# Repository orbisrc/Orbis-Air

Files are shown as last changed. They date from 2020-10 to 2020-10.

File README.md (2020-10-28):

## Orbis-Air



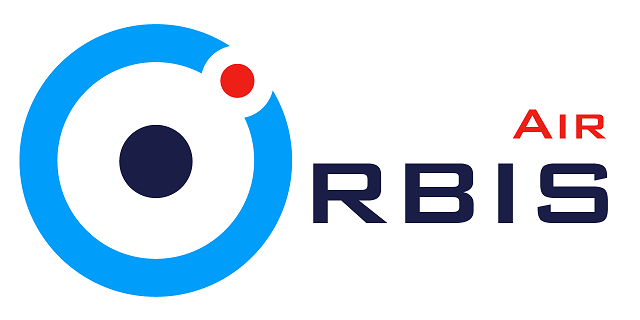
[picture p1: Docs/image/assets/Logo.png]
Orbis-Air


[Youtube: Orbis Air channel in Betaflight](https://youtu.be/BvFRO2qdrkg "Orbis Air channel in Betaflight")

[Youtube: Orbis Air DIY RC Transmitter](https://youtu.be/_WfU4lffqmU "Orbis Air DIY RC Transmitter")

[Thingverse: Orbis Air DIY RC Transmitter](https://www.thingiverse.com/thing:4635528 "Orbis Air DIY RC Transmitter")

Orbis Air is a transmitter project which anyone can make.
It includes:
- Drawings
- Shematic
- Software
- Assembly instructions

### Features
- Transmitter which anyone can make
- Built-in battery with charge from usb
- Connect with simulators via usb
- STM32 F4 processor
- Color 2.4' IPS screen
- Small size
- Gamepad format

### Done
- GUI
- RC channel settings
    - End point
    - Trim
    - Exponents
    - Inversion
    - Channel mapping
- Save/load settings
- Model memory
- Battery low warning
- Inactivity warning
- Screen brightness settings
- Call DFU bootloader from GUI
- PPM generator for external transmitter
- USB-HID for simulators. And tested this in Liftoff
- USB charger

### BOM

- SPI Screen - http://ali.onl/1EDp
- PCB Board STM32F407VET6 - http://ali.onl/1EDh
- Jumper V2 Hall Gimbal http://bgd.onl/7c
- EC11 Encoder http://ali.onl/1EDi
- B5K Potentiometr http://ali.onl/1EDg
- Potentiometr knob http://ali.onl/1EDq
- Micro USB Pcb http://ali.onl/1EDj
- 18500 LiIon battery http://ali.onl/1EDl
- Beeper http://ali.onl/1EDm
- TP5100 Battery charger http://ali.onl/1EDn
- Vibro motor http://ali.onl/1EDo
- DC-DC StepUp MT3608 http://ali.onl/1EDr
- DC-DC StepDown http://ali.onl/1EDs
- Transmitter JR module - Optional.  http://ali.onl/1EDt
- 17mm Pin header http://ali.onl/1EDu
- SMTS-103 or SMTS-102 Switch http://ali.onl/1EDv
- SPST for power switch http://ali.onl/1EDw

### Manual

 1. [Assembly manual](Docs/assembly.md)
 2. [Main schematic](Docs/shematic.md)
 3. [DFU driver install](Docs/dfu_dfivers_install.md)
 4. [Firmware update](Docs/firmware_udate.md)
 5. [First start](Docs/first_start.md)
 
### Developer Channel




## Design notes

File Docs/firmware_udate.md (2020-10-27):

# Firmware update
- Download and install [DfuSeDemo](https://www.st.com/en/development-tools/stsw-stm32080.html) 
- If you are uploading the firmware for the first time, close the BOOT and 3.3V contacts on the MCU PCB. If you need to update the firmware,  "settings -> info -> DFU mode"
- Connect the board to your computer.
- The jumper between BOOT and 3.3V can be removed
- STM32 download inteface will appear in the device manager
- Run DfuSeDemo

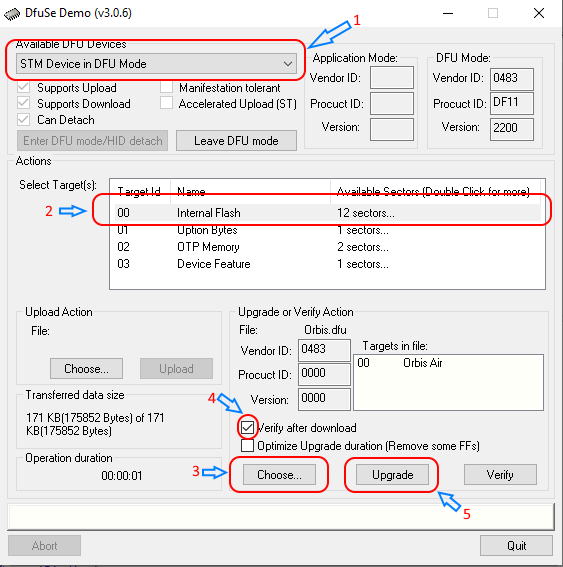
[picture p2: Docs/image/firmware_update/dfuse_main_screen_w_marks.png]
DfuSeDemo

1. Select "DFU Device in DFU Mode" 
2. Select "Internal flash"
3. Choose target firmware
4. Check "Verify after download"
5. Push button "Upgrade"

- After firmware update, turn off and turn on transmitter

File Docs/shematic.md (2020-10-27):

# Main circuit

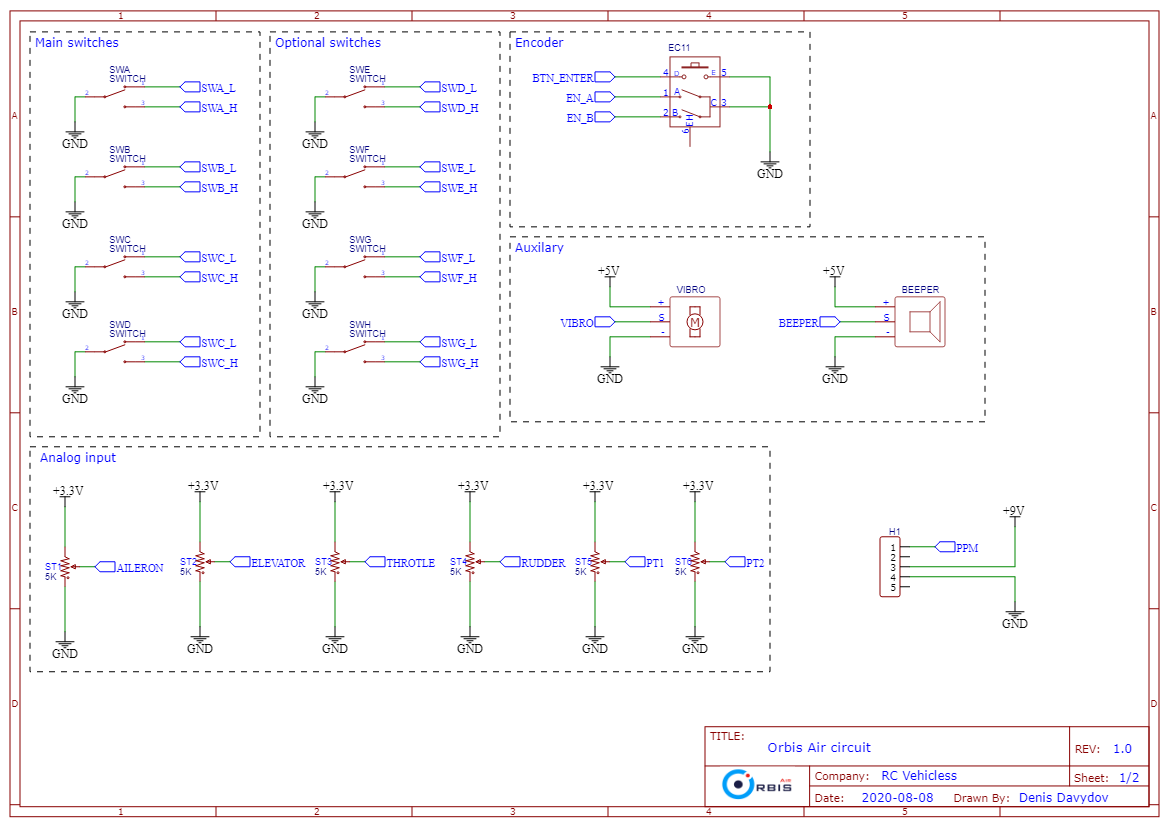
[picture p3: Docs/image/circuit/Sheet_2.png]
Circuit list 1


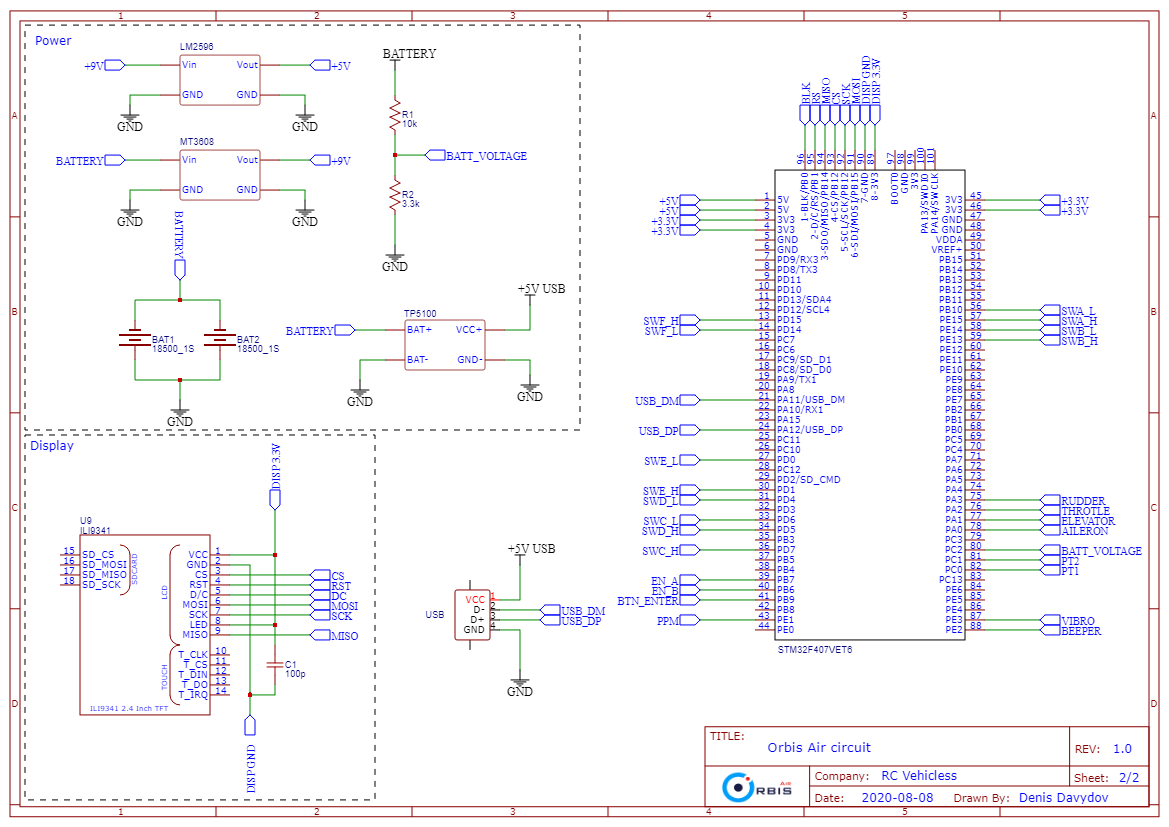
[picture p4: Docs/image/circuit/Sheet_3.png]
Circuit list 2


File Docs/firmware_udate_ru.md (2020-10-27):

# Firmware update
- Скачай и установи утилиту [DfuSeDemo](https://www.st.com/en/development-tools/stsw-stm32080.html) 
- На плате MCU замкни контаты BOOT и 3.3V. 
- Плату подключи к компьютеру. Перемычку между BOOT и 3.3V можно убрать
- В диспетчере устрйоств появится STM32 download inteface. Windows автоматически установит драйвера. 
- Запусти DfuSeDemo

DfuSeDemo
1. Выбери устройство
2. Выбери "Internal flash"
3. Выбери прошивку, которую надо загрузить в устройство.
4. Отметь "Verify after download"
5. Нажми "Upgrade"

- Когда закончится процесс обновления по, выключи и включи устройство

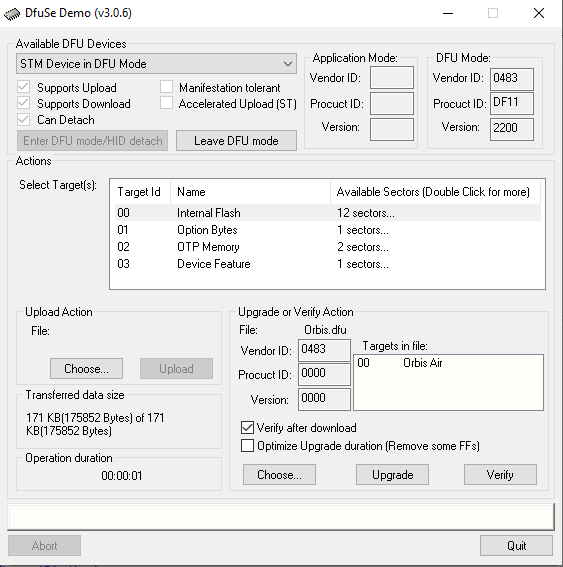
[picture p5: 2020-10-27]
Docs/image/firmware_update/dfuse_main_screen.png

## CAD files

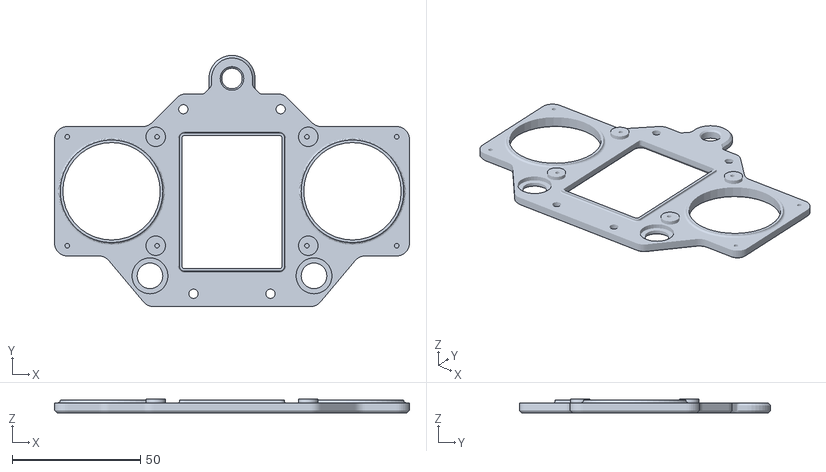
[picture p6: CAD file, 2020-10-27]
STL/rev001/Front panel rev001.STL
138.5 x 98.0 x 5.50

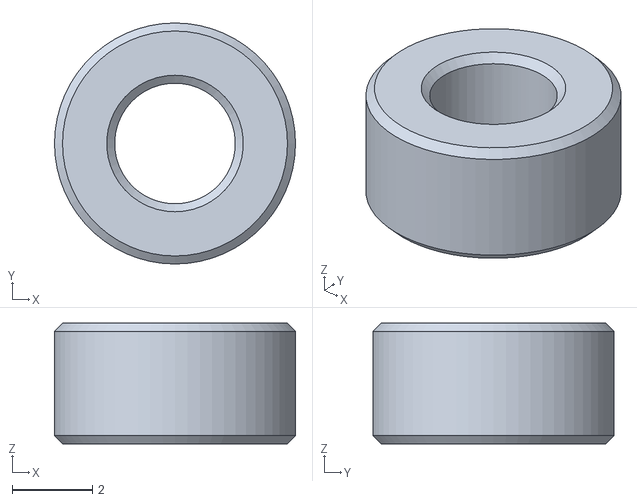
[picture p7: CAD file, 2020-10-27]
STL/rev001/PCB bone rev001.STL
6.00 x 6.00 x 3.00

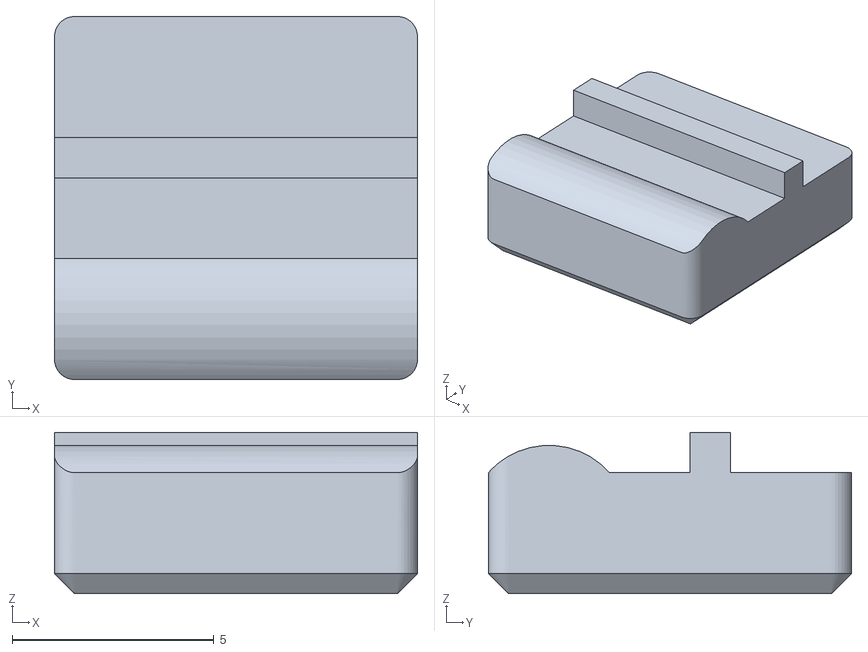
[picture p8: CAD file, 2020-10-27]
STL/rev001/PCB plug rev001.STL
9.00 x 9.00 x 4.00

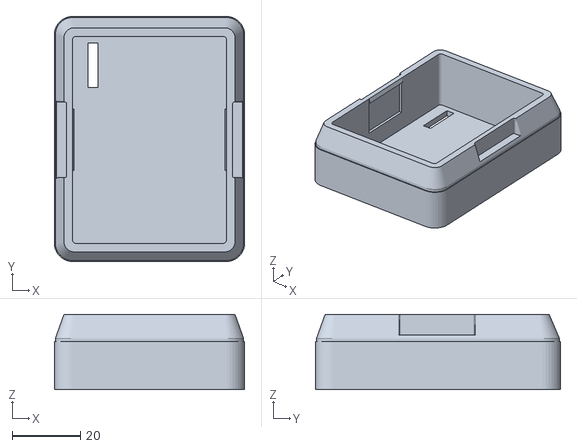
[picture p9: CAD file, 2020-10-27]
STL/rev001/Transmitter mount rev001.STL
55.6 x 71.6 x 22.0

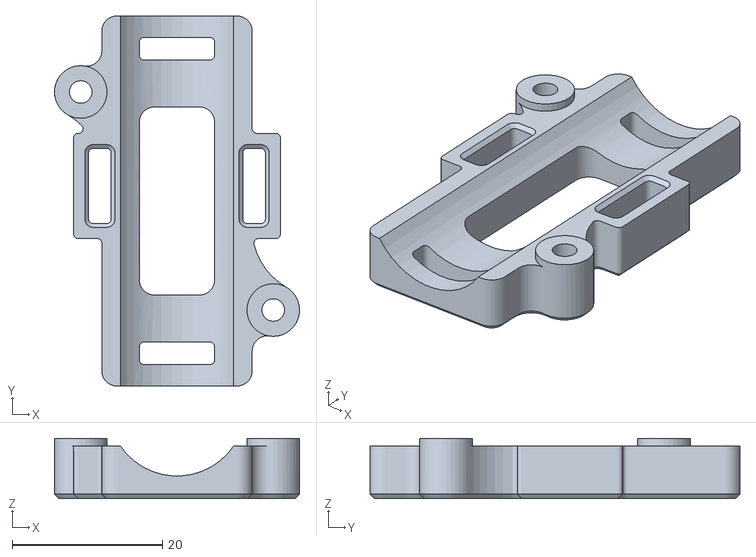
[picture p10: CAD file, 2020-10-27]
STL/rev001/Battery plug left rev001.STL
32.6 x 49.2 x 8.00

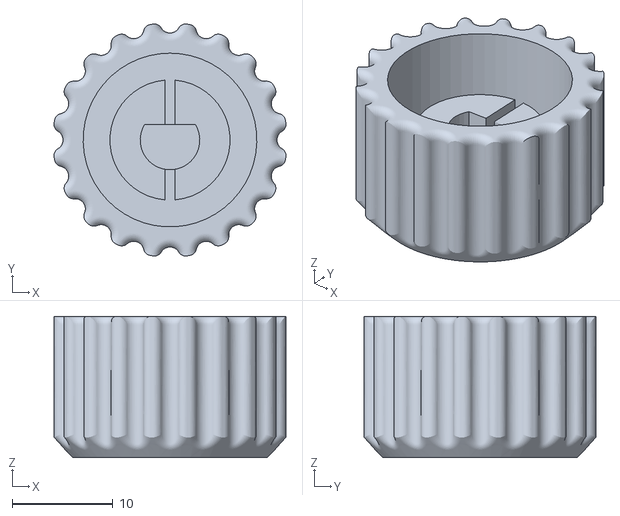
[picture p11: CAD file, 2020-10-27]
STL/rev001/Encoder knob rev001.STL
23.0 x 23.0 x 14.0

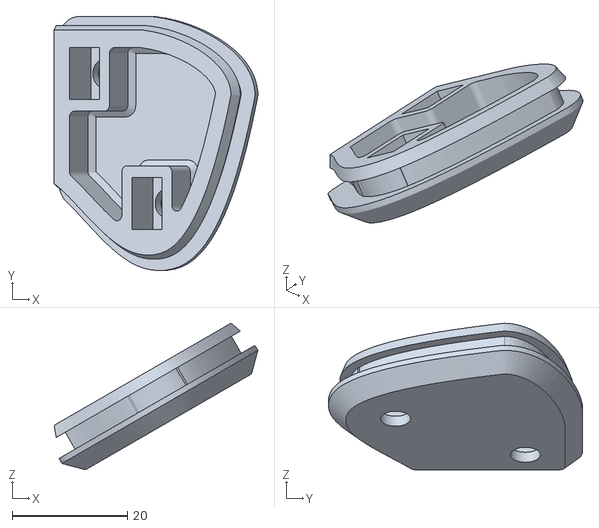
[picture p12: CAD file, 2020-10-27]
STL/rev001/Switch mount rev001.STL
35.3 x 44.0 x 25.4

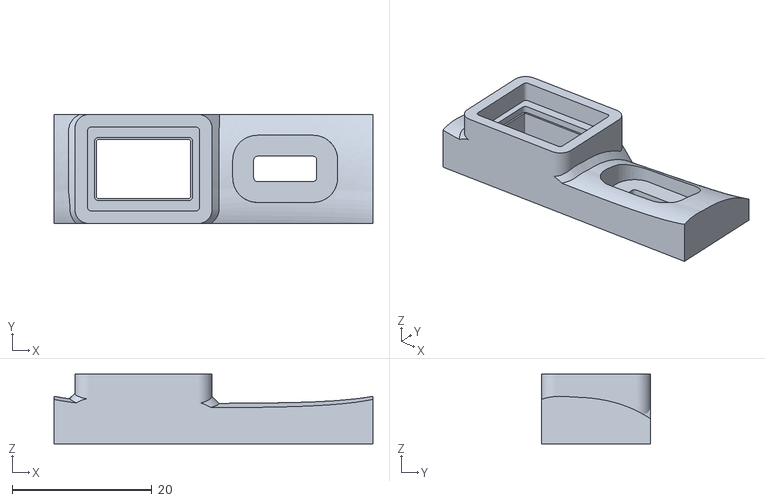
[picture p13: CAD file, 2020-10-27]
STL/rev001/Power switch mount rev001.STL
45.6 x 15.6 x 10.0

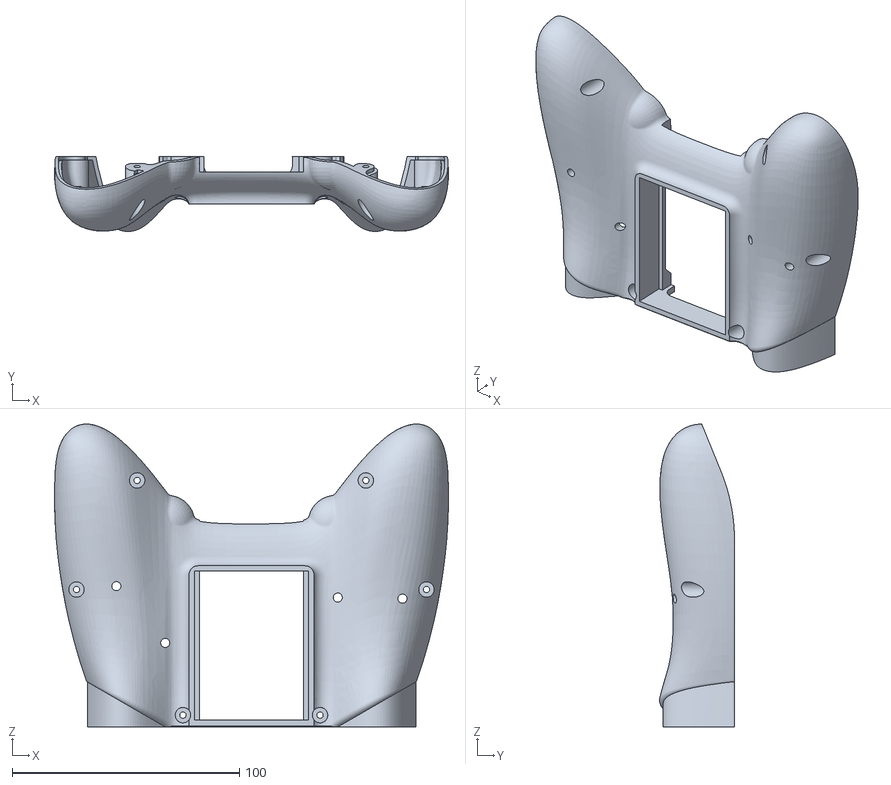
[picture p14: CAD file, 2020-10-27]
STL/rev001/Rear rev001.STL
173.5 x 33.0 x 133.4

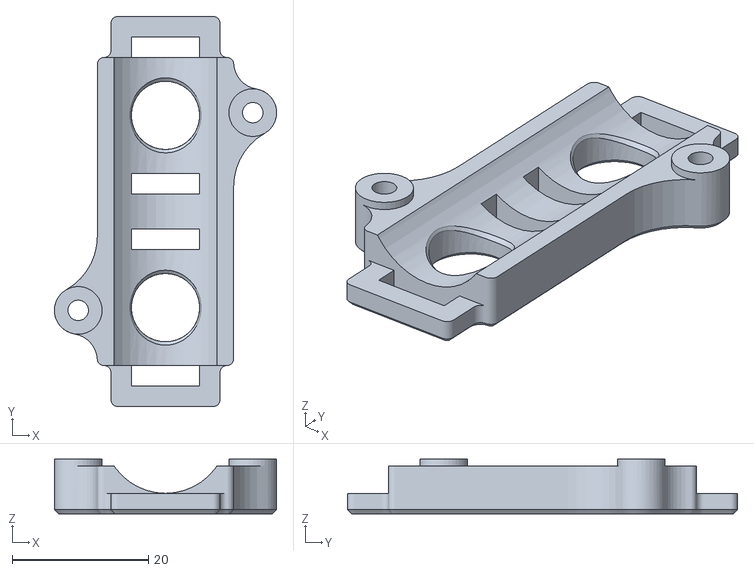
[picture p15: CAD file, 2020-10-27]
STL/rev001/Battery plug right rev001.STL
32.6 x 57.2 x 8.00

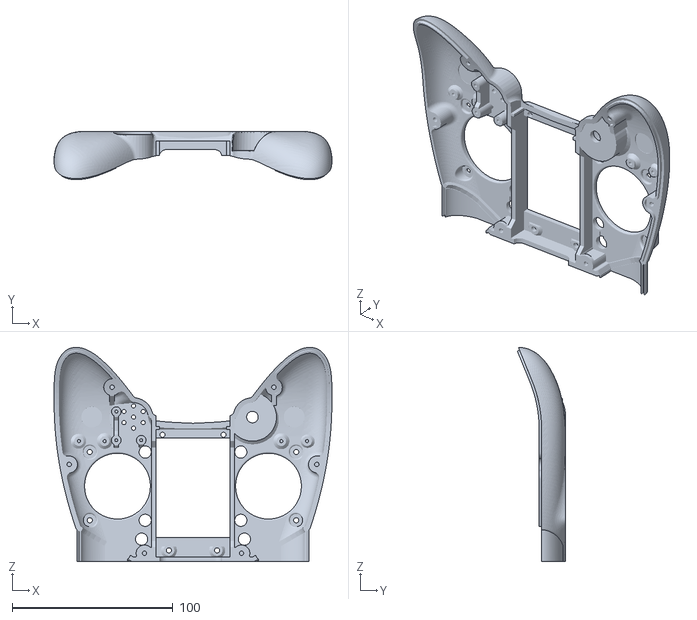
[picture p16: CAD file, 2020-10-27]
STL/rev001/Front rev001.STL
173.1 x 30.1 x 133.4

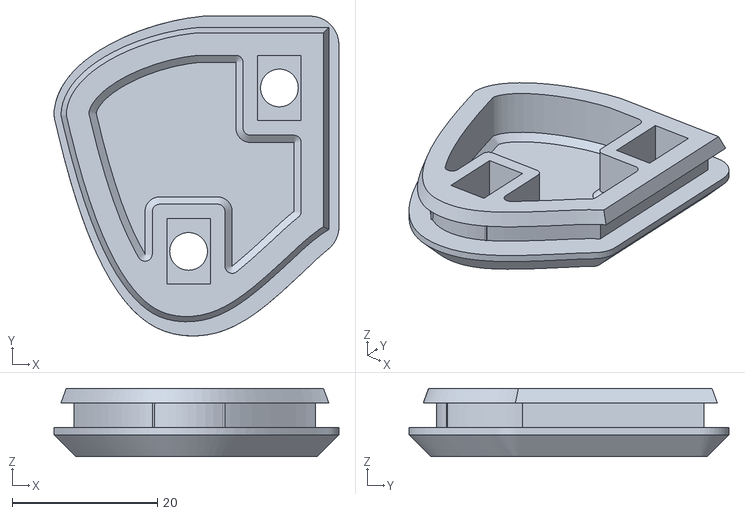
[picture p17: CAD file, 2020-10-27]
STL/rev001/Switch mount left rev001.STL
39.2 x 44.0 x 9.40

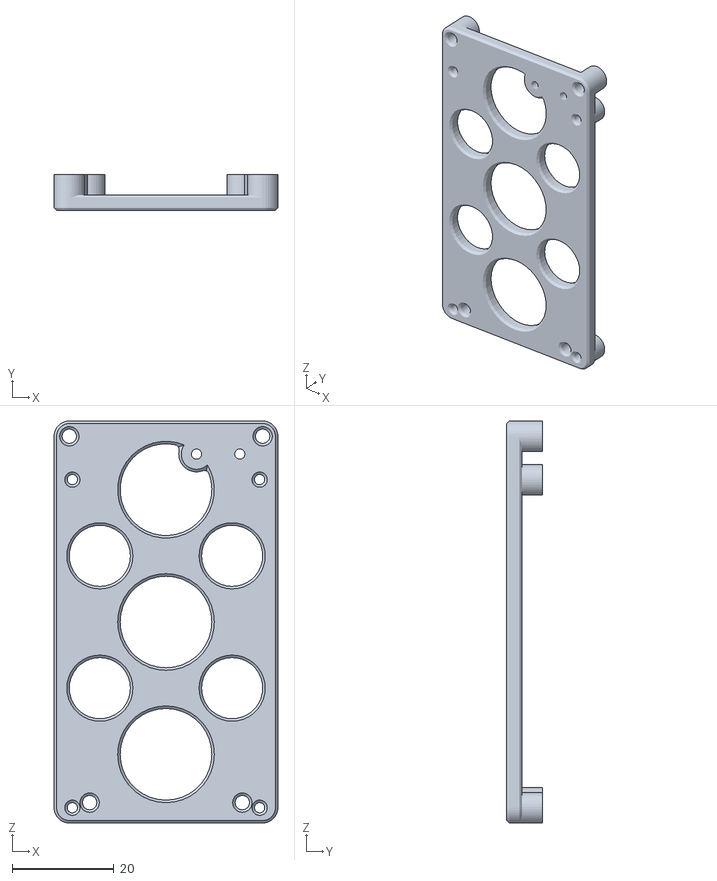
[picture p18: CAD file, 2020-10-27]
STL/rev001/PCB mount rev001.STL
44.0 x 7.00 x 79.0

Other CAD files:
STL/rev001/Switch mount right rev001.STL

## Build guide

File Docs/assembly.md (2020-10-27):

# Assembly guide

Install potentiometers first, then sticks
Step 1

Install the screen and MCU board. Then install the beeper and vibration motor
Step 2

Install ecoder and USB pcb
Step 3

Install batteries in the back of the case. Install the power and charging boards on the battery plug.
Step 4

Install the switches. Connect the two parts
Step 5

Result

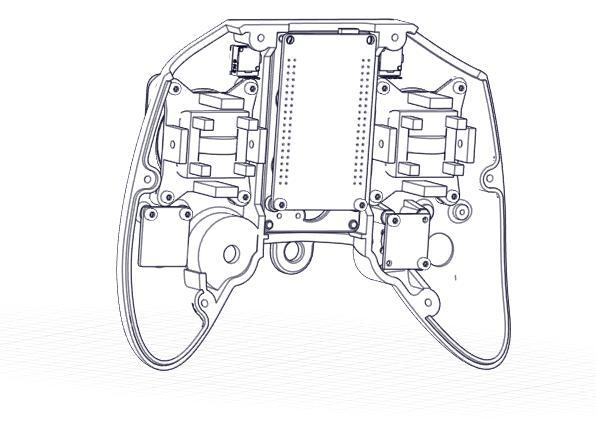
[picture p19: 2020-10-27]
Docs/image/assembly/step2_files/bcd22be432be21f0_image_0.jpg

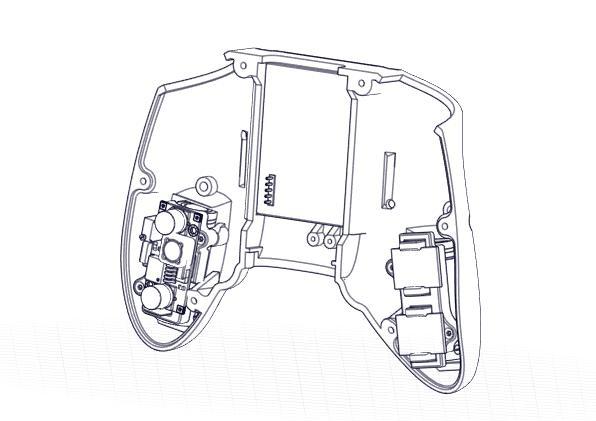
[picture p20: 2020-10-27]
Docs/image/assembly/step4_files/a9ecee0dd4ea2d4b_image_0.jpg

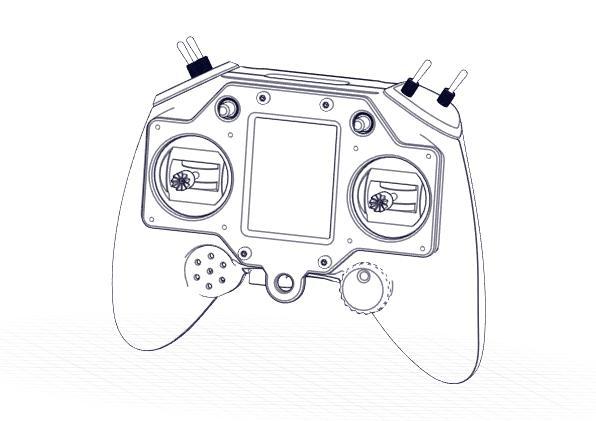
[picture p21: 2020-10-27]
Docs/image/assembly/step5_files/b25a151fcfefb7f9_image_0.jpg

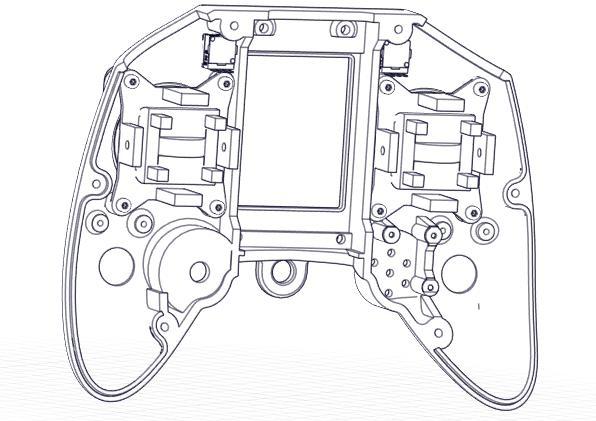
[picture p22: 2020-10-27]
Docs/image/assembly/step1_files/9494430a72263011_image_0.jpg
